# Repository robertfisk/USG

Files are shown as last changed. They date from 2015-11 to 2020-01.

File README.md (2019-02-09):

## The USG is Good, not Bad
The USG is a firewall for your USB ports, protecting your computer from [BadUSB](https://srlabs.de/badusb/). It connects between your computer and your untrusted USB device, isolating the badness and keeping your computer safe.

#### For more info, hit [the Wiki](https://github.com/robertfisk/USG/wiki).

## v1.0 Firmware
This is the firmware branch for the pre-assembled USG v1.0. If you want to build your own USG out of development boards, clone the [v0.9 branch](https://github.com/robertfisk/USG/tree/USG_0.9) instead.

## USG v1.0 hardware
The USG v1.0 is available now from the [online store.](https://globotron.nz/)



## Need More Speed?
The USG is performance-limited due to its USB 1 hardware. If you need to transfer large files from flash drives and hard drives, you need [the Armadillo](https://globotron.nz/products/armadillo-hardware-usb-firewall) instead. Based on the USG's proven open-source technology, the Armadillo is a next-gen device operating at USB 2.0 speed. Available exclusively through the [online store.](https://globotron.nz/products/armadillo-hardware-usb-firewall)



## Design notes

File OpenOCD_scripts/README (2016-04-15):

The OpenOCD scripts in ./board/ are used in-place by the Eclipse debug configurations. You
don't need to copy them anywhere.

If your OpenOCD version is <= 0.8, you will need to copy ./target/stm32f4x.cfg to your OpenOCD
installation's /scripts/target/ folder, replacing the version currently there.
If you have OpenOCD >= 0.9, this is not necessary.

More info for Eclipse OpenOCD configuration:
http://gnuarmeclipse.github.io/debug/openocd/

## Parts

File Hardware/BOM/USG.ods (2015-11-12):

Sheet: Sheet1
Reference | Value | Footprint | Datasheet
U2 | STM32F401xB | USG_footprints:LQFP-64_10x10mm_Pitch0.5mm
C9 | 0.1u | Capacitors_SMD:C_0603
C10 | 0.1u | Capacitors_SMD:C_0603
C11 | 0.1u | Capacitors_SMD:C_0603
C12 | 0.1u | Capacitors_SMD:C_0603
C13 | 0.1u | Capacitors_SMD:C_0603
C5 | 4.7u | Capacitors_SMD:C_0603
C8 | 4.7u | Capacitors_SMD:C_0603
C2 | 18p | Capacitors_SMD:C_0603
C3 | 18p | Capacitors_SMD:C_0603
R5 | 220 | Resistors_SMD:R_0603
Y1 | 8MHz | Crystals:Crystal_HC49-SD_SMD
U3 | AZ1117CH-3.3 | TO_SOT_Packages_SMD:SOT-223
C15 | 22u | Capacitors_SMD:C_0805
C14 | 10u | Capacitors_SMD:C_0805
P1 | USB_A_PLUG | USG_footprints:USB_A_PLUG
R4 | 10k | Resistors_SMD:R_0603
R2 | 1k | Resistors_SMD:R_0603
C1 | 0.1u | Capacitors_SMD:C_0603
BOOT_UPST1 | Jumper_NO_Small | USG_footprints:J_NO_0402
R6 | 10k | Resistors_SMD:R_0603
R8 | 22 | Resistors_SMD:R_0603
R7 | 22 | Resistors_SMD:R_0603
C7 | 0.1u | Capacitors_SMD:C_0603
U1 | NUP4114 | TO_SOT_Packages_SMD:SC-70-6
C6 | 0.1u | Capacitors_SMD:C_0603
JTAG_UPST1 | CONN_02X05 | USG_footprints:Pin_Header_Straight_2x05_Pitch1.27mm
R1 | 220 | Resistors_SMD:R_0603
C4 | 0.1u | Capacitors_SMD:C_0603
FAULT_UPST1 | LED | LEDs:LED-0603
R3 | 1k | Resistors_SMD:R_0603
ID_UPST1 | Jumper_NO_Small | USG_footprints:J_NO_0402
ID_UPST_BOARD0 | Jumper_NC_Small | USG_footprints:J_NC_0402
ID_UPST_BOARD1 | Jumper_NC_Small | USG_footprints:J_NC_0402
ID_UPST_BOARD2 | Jumper_NC_Small | USG_footprints:J_NC_0402
U4 | STM32F401xB | USG_footprints:LQFP-64_10x10mm_Pitch0.5mm
C21 | 0.1u | Capacitors_SMD:C_0603
C22 | 0.1u | Capacitors_SMD:C_0603
C23 | 0.1u | Capacitors_SMD:C_0603
C24 | 0.1u | Capacitors_SMD:C_0603
C25 | 0.1u | Capacitors_SMD:C_0603
C19 | 4.7u | Capacitors_SMD:C_0603
C20 | 4.7u | Capacitors_SMD:C_0603
C17 | 18p | Capacitors_SMD:C_0603
C18 | 18p | Capacitors_SMD:C_0603
R12 | 220 | Resistors_SMD:R_0603
Y2 | 8MHz | Crystals:Crystal_HC49-SD_SMD
P2 | USB_A_SOCKET | USG_footprints:USB_A_SOCKET
R11 | 10k | Resistors_SMD:R_0603
R9 | 1k | Resistors_SMD:R_0603
C16 | 0.1u | Capacitors_SMD:C_0603
BOOT_DNST1 | Jumper_NO_Small | USG_footprints:J_NO_0402
R13 | 10k | Resistors_SMD:R_0603
R15 | 22 | Resistors_SMD:R_0603
R14 | 22 | Resistors_SMD:R_0603
C27 | 0.1u | Capacitors_SMD:C_0603
U5 | NUP4114 | TO_SOT_Packages_SMD:SC-70-6
C26 | 0.1u | Capacitors_SMD:C_0603
JTAG_DNST1 | CONN_02X05 | USG_footprints:Pin_Header_Straight_2x05_Pitch1.27mm
R16 | 220 | Resistors_SMD:R_0603
C28 | 0.1u | Capacitors_SMD:C_0603
FAULT_DNST1 | LED | LEDs:LED-0603
R10 | 1k | Resistors_SMD:R_0603
ID_DNST1 | Jumper_NC_Small | USG_footprints:J_NC_0402
ID_DNST_BOARD0 | Jumper_NC_Small | USG_footprints:J_NC_0402
ID_DNST_BOARD1 | Jumper_NC_Small | USG_footprints:J_NC_0402
ID_DNST_BOARD2 | Jumper_NC_Small | USG_footprints:J_NC_0402
D1 | DOUBLE_DIODE_CCOM | TO_SOT_Packages_SMD:SOT-23
RESET1 | SW_PUSH | USG_footprints:SW_TACT
P3 | USB_OTG | Connect:USB_Micro-B

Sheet: Summarised BOM 1
Reference | Qty | Description | Digikey part | Mfg part
U2, U4 | 2 | STM32F401xB: USG_footprints:LQFP-64_10x10mm_Pitch0.5mm | 497-14047-ND | STM32F401RCT6
C9, C10, C11, C12, C13, C1, C7, C6, C4, C21, C22, C23, C24, C25, C16, C27, C26, C28 | 18 | 0.1u: Capacitors_SMD:C_0603 | 311-1088-1-ND | CC0603KRX7R7BB104
C5, C8, C19, C20 | 4 | 4.7u: Capacitors_SMD:C_0603 | 1276-2087-1-ND | CL10B475KQ8NQNC
C2, C3, C17, C18 | 4 | 18p: Capacitors_SMD:C_0603 | 1276-1089-1-ND | CL10C180JB8NNNC
R5, R1, R12, R16 | 4 | 220: Resistors_SMD:R_0603 | 311-220HRCT-ND | RC0603FR-07220RL
Y1, Y2 | 2 | 8MHz: Crystals:Crystal_HC49-SD_SMD | 535-10212-1-ND | ABLS-8.000MHZ-B4-T
U3 | 1 | AZ1117CH-3.3: TO_SOT_Packages_SMD:SOT-223 | AZ1117CH-3.3TRG1DICT-ND | AZ1117CH-3.3TRG1
C15 | 1 | 22u: Capacitors_SMD:C_0805 | 490-10511-1-ND | GRM21BR61A226ME51L
C14 | 1 | 10u: Capacitors_SMD:C_0805 | 311-1865-1-ND | CC0805KKX5R7BB106
P1 | 1 | USB_A_PLUG: USG_footprints:USB_A_PLUG | 1175-1008-ND | 1001-011-01101
R4, R6, R11, R13 | 4 | 10k: Resistors_SMD:R_0603 | 311-10.0KHRCT-ND | RC0603FR-0710KL
R2, R3, R9, R10 | 4 | 1k: Resistors_SMD:R_0603 | 311-1.00KHRCT-ND | RC0603FR-071KL
R8, R7, R15, R14 | 4 | 22: Resistors_SMD:R_0603 | 311-22.0HRCT-ND | RC0603FR-0722RL
U1, U5 | 2 | NUP4114: TO_SOT_Packages_SMD:SC-70-6 | NUP4114UCW1T2GOSCT-ND | NUP4114UCW1T2G
JTAG_UPST1, JTAG_DNST1 | 2 | CONN_02X05: USG_footprints:Pin_Header_Straight_2x05_Pitch1.27mm | 1175-1627-ND | 3220-10-0100-00
FAULT_UPST1, FAULT_DNST1 | 2 | LED: LEDs:LED-0603 | 160-1434-1-ND | LTST-C190KFKT
P2 | 1 | USB_A_SOCKET: USG_footprints:USB_A_SOCKET | UE27AC54100-ND | UE27AC54100
D1 | 1 | DOUBLE_DIODE_CCOM: TO_SOT_Packages_SMD:SOT-23 | BAV70LT1GOSCT-ND | BAV70LT1G
RESET1 | 1 | SW_PUSH: USG_footprints:SW_TACT | 450-1804-ND | 1825910-7
P3 | 1 | USB_OTG: Connect:USB_Micro-B | 609-4618-1-ND | 10118194-0001LF

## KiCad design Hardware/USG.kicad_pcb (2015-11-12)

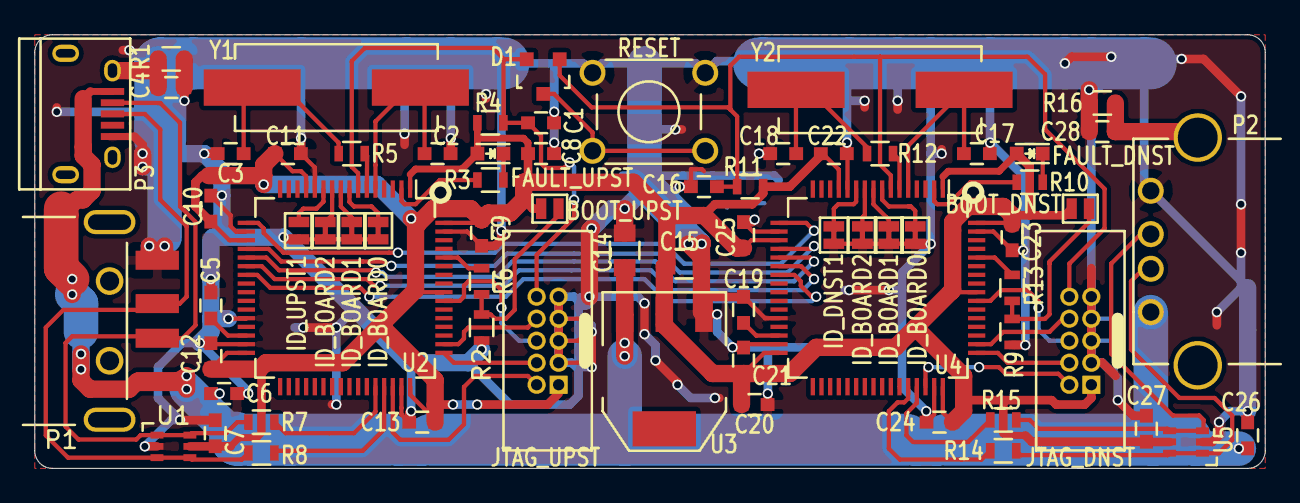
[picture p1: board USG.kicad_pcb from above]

Board: 2 copper layers, 71.0 x 25.0 mm, 70 parts (0 on the bottom side), 53 nets.

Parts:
BOOT_DNST: Jumper_NO_Small; J_NO_0402
BOOT_UPST: Jumper_NO_Small; J_NO_0402
C1, C4, C6, C7, C9, C10, C11, C12, C13, C16, C21, C22, C23, C24, C25, C26, C27, C28: 0.1u; C_0603
C2, C3, C17, C18: 18p; C_0603
C5, C8, C19, C20: 4.7u; C_0603
C14: 10u; C_0805
C15: 22u; C_0805
D1: DOUBLE_DIODE_CCOM; SOT-23
FAULT_DNST: LED; LED-0603
FAULT_UPST: LED; LED-0603
ID_BOARD0, ID_BOARD0#2, ID_BOARD1, ID_BOARD1#2, ID_BOARD2, ID_BOARD2#2: Jumper_NC_Small; J_NC_0402
ID_DNST1: Jumper_NC_Small; J_NC_0402
ID_UPST1: Jumper_NO_Small; J_NO_0402
JTAG_DNST: CONN_02X05; Pin_Header_Straight_2x05_Pitch1.27mm
JTAG_UPST: CONN_02X05; Pin_Header_Straight_2x05_Pitch1.27mm
P1: USB_A_PLUG
P2: USB_A_SOCKET
P3: USB_OTG; USB_Micro-B
R1, R5, R12, R16: 220; R_0603
R2, R3, R9, R10: 1k; R_0603
R4, R6, R11, R13: 10k; R_0603
R7, R8, R14, R15: 22; R_0603
RESET: SW_PUSH; SW_TACT
U1, U5: NUP4114; SC-70-6
U2, U4: STM32F401xB; LQFP-64_10x10mm_Pitch0.5mm
U3: AZ1117CH-3.3; SOT-223
Y1, Y2: 8MHz; Crystal_HC49-SD_SMD

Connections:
+3V3: BOOT_DNST.2, BOOT_UPST.2, C7.1, C8.1, C9.2, C10.2, C11.2, C12.2, C13.2, C15.1, C20.1, C21.2, C22.2, C23.2, C24.2, C25.2, C27.1, FAULT_DNST.2, FAULT_UPST.2, JTAG_DNST.1, JTAG_UPST.1, R4.1, R11.1, U1.5, U2.1, U2.13, U2.19, U2.32, U2.48, U2.56, U2.64, U3.2, U4.1, U4.13, U4.19, U4.32, U4.48, U4.56, U4.64, U5.5
+5V: C6.1, C14.1, C26.1, P1.1, P2.1, P3.1, U3.3
/JTCK_DNST: JTAG_DNST.4, U4.49
/JTCK_UPST: JTAG_UPST.4, U2.49
/JTDI_DNST: JTAG_DNST.8, U4.50
/JTDI_UPST: JTAG_UPST.8, U2.50
/JTDO_DNST: JTAG_DNST.6, U4.55
/JTDO_UPST: JTAG_UPST.6, U2.55
/JTMS_DNST: JTAG_DNST.2, U4.46
/JTMS_UPST: JTAG_UPST.2, U2.46
/RESET_DNST: C16.1, D1.1, JTAG_DNST.10, R11.2, U4.7
/RESET_UPST: C1.1, D1.2, JTAG_UPST.10, R4.2, U2.7
/SPI_MISO: U2.22, U4.22
/SPI_MOSI: U2.23, U4.23
/SPI_NSS: U2.20, U4.20
/SPI_SCK: U2.21, U4.21
/SPI_TX_OK: U2.17, U4.17
GND: C1.2, C2.2, C3.2, C4.2, C5.2, C6.2, C7.2, C8.2, C9.1, C10.1, C11.1, C12.1, C13.1, C14.2, C15.2, C16.2, C17.2, C18.2, C19.2, C20.2, C21.1, C22.1, C23.1, C24.1, C25.1, C26.2, C27.2, C28.2, ID_BOARD0.1, ID_BOARD0#2.1, ID_BOARD1.1, ID_BOARD1#2.1, ID_BOARD2.1, ID_BOARD2#2.1, ID_DNST1.1, ID_UPST1.1, JTAG_DNST.3, JTAG_DNST.5, JTAG_DNST.7, JTAG_DNST.9, JTAG_UPST.3, JTAG_UPST.5, JTAG_UPST.7, JTAG_UPST.9, P1.4, P2.4, P3.5, R1.2, R2.2, R9.2, R16.2, RESET.1, U1.2, U2.12, U2.18, U2.28, U2.31, U2.47, U2.63, U3.1, U4.12, U4.18, U4.28, U4.31, U4.47, U4.63, U5.2
unnamed: BOOT_DNST.1, R9.1, R13.2
unnamed: BOOT_UPST.1, R2.1, R6.2
unnamed: C2.1, U2.5, Y1.1
unnamed: C3.1, R5.2, Y1.2
unnamed: C4.1, P1.5, P3.6, R1.1
unnamed: C5.1, U2.30
unnamed: C17.1, U4.5, Y2.1
unnamed: C18.1, R12.2, Y2.2
unnamed: C19.1, U4.30
unnamed: C28.1, P2.5, R16.1
unnamed: D1.3, RESET.2
unnamed: FAULT_DNST.1, R10.2
unnamed: FAULT_UPST.1, R3.2
unnamed: ID_DNST1.2, U4.11
unnamed: ID_BOARD0.2, U4.8
unnamed: ID_BOARD1.2, U4.9
unnamed: ID_BOARD2.2, U4.10
unnamed: ID_UPST1.2, U2.11
unnamed: ID_BOARD0#2.2, U2.8
unnamed: ID_BOARD1#2.2, U2.9
unnamed: ID_BOARD2#2.2, U2.10
unnamed: P1.2, P3.2, R7.1, U1.1, U1.6
unnamed: P1.3, P3.3, R8.1, U1.3, U1.4
unnamed: P2.2, R14.1, U5.1, U5.6
unnamed: P2.3, R15.1, U5.3, U5.4
unnamed: R3.1, U2.2
unnamed: R5.1, U2.6
unnamed: R6.1, U2.60
unnamed: R7.2, U2.44
unnamed: R8.2, U2.45
unnamed: R10.1, U4.2
unnamed: R12.1, U4.6
unnamed: R13.1, U4.60
unnamed: R14.2, U4.44
unnamed: R15.2, U4.45

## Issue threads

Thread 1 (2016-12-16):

Add small 1GB boot drive for Anti Evil Maid

tasket, 2016-12-16:
It would be nice to have a single device that could both isolate the keyboard and boot the machine via Qubes AEM.

robertfisk, 2016-12-18:
From a purely practical perspective, this can be done for a modest per-unit price by adding a microSD socket to the USG, and connecting it to the downstream (device-side) embedded CPU. This will require another PCB revision with associated prototyping and stock management costs. It would also require extending the internal SPI-bus protocol to support two simultaneous device classes (mass-storage + something else). At the current rate of development this is likely to be 12+ months away :)

**However!** The security implications of this value-add feature should not be underestimated.

1. Obviously there is now no security boundary between your keyboard and your AEM storage. A bad keyboard can attack the SD card's firmware, and potentially vice versa (I'm not sure whether the SD card protocol is sufficiently complex to facilitate an exploit, but USB certainly is).

2. _The killer issue IMO:_ The USG allows only one device to be active at any one time, specifically to block [hidden device attacks.](https://github.com/robertfisk/USG/wiki#type-2-attacks-hidden-evil-functionality) However, implementing microSD card support in the USG firmware means that any badUSB device can now pass through an additional mass storage device at any time. This blows a big hole through the "one active device" rule, and weakens the USG's security stance.

Even simply implementing this feature in an alternative firmware version will lead to reduced trust in the USG. The factory may load in the microSD-supporting fimrware by accident, and the user has no way to verify which firmware was installed without actually exploiting the USG themselves!

So I'm going to leave this issue open, but I will need to address the concerns above before implementing this feature.

virtualguy, 2016-12-18:
How about two downstream microcontrollers, one as a mass storage device and another as the target USB device. Perhaps even on different SPI ports for a little more isolation.

robertfisk, 2016-12-19:
Yes, it would require two downstream MCUs to do this securely. That way the uncompromised upstream MCU can differentiate between a bad keyboard, and legitimate mass storage / SD cards.

Of course this would significantly increase cost, and the PCB will not fit in the current plastic case. It would essentially be an entirely new product.

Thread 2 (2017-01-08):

Upstream Freakout in mass storage mode on Win10

robertfisk, 2017-01-08:
- Connected fat32 formatted flash drive to Win10 machine.
- Got a popup saying drive needs a scan.
- Ignored popup, did not attempt to access the drive.
- Approx 30sec later, Upstream MCU freaked out (red flashing LED on USG v1.0)
- Removed and reinserted flash drive, ran scan as requested, scan finished and everything fine. Cannot trivially reproduce.

Generally speaking, Upstream should not freak out in any circumstance. If I or anyone else sees this happen I will investigate further. Until then this will be a low priority.

robertfisk, 2017-03-12:
Low priority issues have a way of becoming high priority when they keep appearing during production. Argh!

So it turns out this was not specific to Win10, appearing (occasionally) during mass storage writes on any OS. It was caused by unreliable USB host controller operation inside the STM32 with write transactions containing more than one 64-byte packet. Reverting to single-packet writes resolved the issue at the expense of some write speed.

This issue is resolved in firmware release r03.

Closed 2017-03-12.

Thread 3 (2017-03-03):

Implement read-only mass storage mode

robertfisk, 2017-03-03:
Various use-cases (forensics, enhanced paranoia) have a need for a read-only mass storage mode. This could be either a compile-time option, or dynamically set on bootup based on an input pin controlled by the user.

Both Upstream and Downstream would need to be put into read-only mode to ensure robustness in the face of USB exploits coming from either direction.

teeks99, 2017-03-12:
I think this is an awesome idea, this device seems like it would be perfect to implement it. I frequently need to use drives like the [Kanguru](https://www.amazon.com/Kanguru-Solutions-Flash-Write-Protect-KF3WP-32G/dp/B008OGNMEI) with a write-protect switch when transferring data onto a system that stores high-value data. This is done with the hope that if malware were to infect this high-value data system, it wouldn't have any way to ex-filtrate the data. However, ever since the revelation of BadUSB, I've been very worried about a virus being able to just overwrite the firmware to disable the input from this write-protect switch. Even though it is a physical switch, I'm sure that switch doesn't directly control the hardware that charges the write capacitors on the media, or anything like that. I'd bet my bottom dollar that physical switch just gives an input to the firmware...which could be hacked by BadUSB or the like.

However, I'm not sure there would be a benefit in putting downstream (device side) into read-only mode. Does that mean that data couldn't be passed from the mass-storage device to the pc? If so, I believe it would effectively prevent usage of the device completely...don't you need to read data to the file system before you preform writes to the device? I guess you could maybe use that mode to format devices, but even then you'd want some status back.

With the separation of the upstream and downstream sides here, it seems like there would be a place where we could read a switch telling the USG to go to read-only mode for the media, and could then filter any commands coming from the PC sending file data to the media. However, this would need to be in a section of firmware that is protected from manipulation by *either* end of the connection. From reading the documentation I'm unsure if such a place exists on the device. It seems like this is only upstream and downstream firmware, ideally this firewall would be in neither of those as it would be possible for there to be malicious code on *both* ends at the same time. Hope that doesn't grow the scope of the problem too much :-)

robertfisk, 2017-03-15:
I'll take that as a +1 !

I agree that the write protection on common devices is a flag to the firmware, which could be overridden. You can also get forensic 'write blockers'. I have not looked inside one of these, but unless they are built to the same spec as the USG with independent processors, they will also be vulnerable to compromise.

Regarding putting Upstream and Downstream into read-only mode, this would allow reads from the PC through to the device. I agree doing it any other way won't make sense.

Having both Upstream and Downstream agree to disable writes is important in a variety of scenarios:
1. Malware on PC wants to exfiltrate data. Writes are blocked by Upstream.
2. USG-aware malware on PC wants to exfiltrate data. Malware compromises Upstream, but writes are blocked by Downstream.
3. USG-aware BadUSB device wants to disable write protection. BadUSB device compromises Downstream, but writes are blocked by Upstream.

However there is a fourth scenario where things get ugly: USG-aware malware on PC wants to exfiltrate data to USG-aware BadUSB device. In this case both Upstream and Downstream are compromised and we no longer have control. You could have a third 'referee' microcontroller monitoring the SPI bus and blowing the whistle when it sees write commands. But the attacker can easily avoid this by coding a sequence of 'read' commands that actually transmit data to write. In this case we are owned.

So the takeaway is to make sure that the attacker who controls your PC is not cooperating with the attacker who controls your USB storage. Second-sourcing is important!

robertfisk, 2017-07-22:
This feature is now implemented as a compile-time option! Writes can be disabled by commenting out this line...

`#define CONFIG_MASS_STORAGE_WRITES_PERMITTED`

in the files:

`Upstream/Inc/build_config.h`
`Downstream/Inc/build_config.h`

(be sure to make the same change to both files, for maximum malware resistance)

Support for mass storage, keyboards, and mice can be selectively disabled by commenting out other defines in the files above.

Closed 2017-07-22.

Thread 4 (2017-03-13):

Mass storage device reduced size

marmarek, 2017-03-13:
Looks like USG incorrectly send device size information - always it's one block smaller:

Raw device:
```
usb-storage 3-1.2:1.0: USB Mass Storage device detected
scsi host6: usb-storage 3-1.2:1.0
scsi 6:0:0:0: Direct-Access     Generic  Flash Disk       5.00 PQ: 0 ANSI: 2
sd 6:0:0:0: Attached scsi generic sg0 type 0
sd 6:0:0:0: [sda] 4096000 512-byte logical blocks: (2.10 GB/1.95 GiB)
sd 6:0:0:0: [sda] Write Protect is off
sd 6:0:0:0: [sda] Mode Sense: 0b 00 00 08
sd 6:0:0:0: [sda] No Caching mode page found
sd 6:0:0:0: [sda] Assuming drive cache: write through
 sda: sda1
sd 6:0:0:0: [sda] Attached SCSI removable disk
```

With USG:
```
scsi 7:0:0:0: Direct-Access     The USG  is Good, not bad v1.0 PQ: 0 ANSI: 2
sd 7:0:0:0: Attached scsi generic sg0 type 0
sd 7:0:0:0: [sda] 4095999 512-byte logical blocks: (2.10 GB/1.95 GiB)
sd 7:0:0:0: [sda] Write Protect is off
sd 7:0:0:0: [sda] Mode Sense: 00 00 00 00
sd 7:0:0:0: [sda] Asking for cache data failed
sd 7:0:0:0: [sda] Assuming drive cache: write through
 sda: sda1
sda: p1 size 4095968 extends beyond EOD, enabling native capacity
 sda: sda1
sda: p1 size 4095968 extends beyond EOD, truncated
sd 7:0:0:0: [sda] Attached SCSI removable disk
```

robertfisk, 2017-03-14:
It turns out the SCSI ReadCapacity10 command does not return the device capacity. It returns the address of the last block, which is (capacity - 1). I'm totally going to blame ST's USB host stack for this bug! (the USB device stack correctly subtracted one from the block count, hence shrinking devices)

Issue is fixed in tag 1.0r03b.

Closed 2017-03-14.

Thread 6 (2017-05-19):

Initialization problem on v0.9 Upstream board

robertfisk, 2017-05-19:
A user reported their DIY v0.9 running 0.9r03 firmware was not working. Upstream was stuck in the CheckFirmwareMatchesHardware() function on bootup.

We determined this was due to the PC12-pullup check failing (implying that the firmware was not running on a H405 board). Bypassing the PC12 check allowed normal functionality.

We need to determine if this issue can be fixed with a delay in the PC12 check, and how much delay is required. Or whether the issue is due to a logic threshold change, in which case we probably want to find another way to confirm we are running on a H405 board.

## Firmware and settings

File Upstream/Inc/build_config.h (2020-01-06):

/*
 * build_config.h
 *
 *  Created on: Jun 20, 2017
 *      Author: Robert Fisk
 *
 * This Source Code Form is subject to the terms of the Mozilla Public
 * License, v. 2.0. If a copy of the MPL was not distributed with this
 * file, You can obtain one at https://mozilla.org/MPL/2.0/.
 */

#ifndef INC_BUILD_CONFIG_H_
#define INC_BUILD_CONFIG_H_


#define CONFIG_MASS_STORAGE_ENABLED
#define CONFIG_MASS_STORAGE_WRITES_PERMITTED

#define CONFIG_KEYBOARD_ENABLED
#define CONFIG_KEYBOARD_BOT_DETECT_ENABLED

#define CONFIG_MOUSE_ENABLED
#define CONFIG_MOUSE_BOT_DETECT_ENABLED

#define CONFIG_WRITE_FLASH_TIME_MS                          3000        //Enable write LED flashes for the specified length of time



//Configure keyboard bot detection here:
#ifdef CONFIG_KEYBOARD_BOT_DETECT_ENABLED
    //-----------------------------------------------------------
    //Adjust this threshold first to tune keyboard bot detection. Lower values = more sensitive
    #define KEYBOARD_BOTDETECT_LOCKOUT_BIN_THRESHOLD        5       //4 is a good setting for the paranoid. 5 is good for the average user who doesn't want to encounter a rare false-positive.
    //-----------------------------------------------------------

    #define KEYBOARD_BOTDETECT_FAST_BIN_WIDTH_MS            10      //10ms per bin
    #define KEYBOARD_BOTDETECT_SLOW_BIN_WIDTH_MS            20      //20ms per bin
    #define KEYBOARD_BOTDETECT_FAST_BIN_COUNT               30      //30 bins at 10ms = 300ms fast coverage
    #define KEYBOARD_BOTDETECT_SLOW_BIN_COUNT               50      //50 bins at 20ms = 1 sec slow coverage, wrapped
    #define KEYBOARD_BOTDETECT_FAST_BIN_DRAIN_DIVIDER       2
    #define KEYBOARD_BOTDETECT_SLOW_BIN_DRAIN_DIVIDER       4
#endif


//Configure mouse bot detection here:
#ifdef CONFIG_MOUSE_BOT_DETECT_ENABLED
    #define MOUSE_BOTDETECT_VELOCITY_MULTIPLIER             10

    //Jump detection stuff
    #define MOUSE_BOTDETECT_JUMP_VELOCITY_THRESHOLD         20      //Varies by mouse. Most short jumps are <= 10 velocity
    #define MOUSE_BOTDETECT_JUMP_PERIODS                    4

    //Constant acceleration detection stuff
    #define MOUSE_BOTDETECT_CONSTANT_ACCEL_LOCKOUT          300     //Lock when constant acceleration counter reaches this number
    #define MOUSE_BOTDETECT_CONSTANT_ACCEL_STOP             100     //Block mouse movements when counter is above this value
    #define MOUSE_BOTDETECT_CONSTANT_ACCEL_CREDIT           100     //Non-constant-acceleration movements can build a credit that will be used before hitting the limits above. Handy for mice or users that exhibit constant velocity characteristics mid-movement.
    #define MOUSE_BOTDETECT_VELOCITY_RESET_TIMEOUT_MS       3000    //Reset constant acceleration counter when mouse stops for this time

    #define MOUSE_BOTDETECT_VELOCITY_HISTORY_SIZE           12
    #define MOUSE_BOTDETECT_VELOCITY_MATCH_BASE             256
    #define MOUSE_BOTDETECT_VELOCITY_MATCH_ERROR            6

    //Jiggle detection stuff
    #define MOUSE_BOTDETECT_JIGGLE_STOP_PERIODS             10
    #define MOUSE_BOTDETECT_JIGGLE_BIN_WIDTH_MS             20      //20ms per bin
    #define MOUSE_BOTDETECT_JIGGLE_BIN_COUNT                50      //50 bins at 20ms = 1 sec coverage, wrapped
    #define MOUSE_BOTDETECT_JIGGLE_BIN_DIVIDER              3
    #define MOUSE_BOTDETECT_LOCKOUT_JIGGLE_BIN_THRESHOLD    4
#endif


//Configuration common to all bot detectors
#if defined CONFIG_KEYBOARD_BOT_DETECT_ENABLED || defined CONFIG_MOUSE_BOT_DETECT_ENABLED
    #define BOTDETECT_TEMPORARY_LOCKOUT_TIME_MS             4000    //Lock keyboard/mouse for 4 seconds as a first warning
    #define BOTDETECT_TEMPORARY_LOCKOUT_FLASH_TIME_MS       60000   //Flash fault LED for 60 seconds after warning lockout
#endif


#endif /* INC_BUILD_CONFIG_H_ */

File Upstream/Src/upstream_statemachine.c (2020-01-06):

/*
 * upstream_statemachine.c
 *
 *  Created on: 20/08/2015
 *      Author: Robert Fisk
 *
 * This Source Code Form is subject to the terms of the Mozilla Public
 * License, v. 2.0. If a copy of the MPL was not distributed with this
 * file, You can obtain one at https://mozilla.org/MPL/2.0/.
 */


#include "upstream_statemachine.h"
#include "upstream_spi.h"
#include "upstream_hid.h"
#include "usb_device.h"
#include "usbd_core.h"
#include "usbd_msc.h"
#include "usbd_hid.h"
#include "build_config.h"

#define POLL_DEVICE_CONNECTED_TIMEOUT_MS    1000


UpstreamStateTypeDef            UpstreamState           = STATE_TEST_INTERFACE;
InterfaceCommandClassTypeDef    ConfiguredDeviceClass   = COMMAND_CLASS_INTERFACE;
uint32_t                        PollDeviceConnectedTimer;


void Upstream_StateMachine_TestInterfaceReplyCallback(UpstreamPacketTypeDef* replyPacket);
void Upstream_StateMachine_NotifyDevice(UpstreamPacketTypeDef* freePacket);
void Upstream_StateMachine_NotifyDeviceReplyCallback(UpstreamPacketTypeDef* replyPacket);
void Upstream_StateMachine_PollDeviceConnectedReplyCallback(UpstreamPacketTypeDef* replyPacket);



void Upstream_InitStateMachine(void)
{
    UpstreamPacketTypeDef* freePacket;
    uint16_t i;
    uint8_t  testDataValue;

    Upstream_InitSPI();

    //Prepare SPI test packet
    freePacket = Upstream_GetFreePacketImmediately();
    if (freePacket == NULL)
    {
        UpstreamState = STATE_ERROR;
        return;
    }

    freePacket->Length16 = UPSTREAM_PACKET_LEN_16;
    freePacket->CommandClass = COMMAND_CLASS_INTERFACE;
    freePacket->Command = COMMAND_INTERFACE_ECHO;

    //Fill our test packet with some junk
    testDataValue = 0xFF;
    for (i = 0; i < MSC_MEDIA_PACKET; i++)
    {
        freePacket->Data[i] = testDataValue;
        testDataValue += 39;
    }

    if (Upstream_TransmitPacket(freePacket) == HAL_OK)
    {
        Upstream_ReceivePacket(Upstream_StateMachine_TestInterfaceReplyCallback);
    }
}


//Used by upstream_spi freakout macro, indicates we should stop everything.
void Upstream_StateMachine_SetErrorState(void)
{
    UpstreamState = STATE_ERROR;
    if ((ConfiguredDeviceClass > COMMAND_CLASS_INTERFACE) &&
        (ConfiguredDeviceClass < COMMAND_CLASS_ERROR))
    {
        USBD_DeInit(&hUsbDeviceFS);
    }
}


InterfaceCommandClassTypeDef Upstream_StateMachine_CheckActiveClass(void)
{
    if (UpstreamState == STATE_ERROR)
    {
        return COMMAND_CLASS_ERROR;
    }

    if ((UpstreamState == STATE_DEVICE_ACTIVE) ||
        (UpstreamState == STATE_SUSPENDED))
    {
        return ConfiguredDeviceClass;
    }

    //else:
    UPSTREAM_STATEMACHINE_FREAKOUT;
    return COMMAND_CLASS_INTERFACE;
}


uint32_t Upstream_StateMachine_GetSuspendState(void)
{
    if (UpstreamState == STATE_SUSPENDED)
    {
        return 1;
    }
    return 0;
}


void Upstream_StateMachine_TestInterfaceReplyCallback(UpstreamPacketTypeDef* replyPacket)
{
    uint16_t i;
    uint8_t  testDataValue;

    if (UpstreamState >= STATE_ERROR)
    {
        return;
    }

    if ((UpstreamState != STATE_TEST_INTERFACE) ||
        (replyPacket == NULL))
    {
        UPSTREAM_STATEMACHINE_FREAKOUT;
        return;
    }

    if (replyPacket->Length16 != UPSTREAM_PACKET_LEN_16)
    {
        UPSTREAM_STATEMACHINE_FREAKOUT;
        return;
    }

    testDataValue = 0xFF;
    for (i = 0; i < MSC_MEDIA_PACKET; i++)
    {
        if (replyPacket->Data[i] != testDataValue)
        {
            UPSTREAM_STATEMACHINE_FREAKOUT;
            return;
        }
        testDataValue += 39;
    }

    //SPI interface passed checks. Now we wait for a device to be attached to downstream.
    Upstream_StateMachine_NotifyDevice(replyPacket);
}


void Upstream_StateMachine_NotifyDevice(UpstreamPacketTypeDef* freePacket)
{
    UpstreamState = STATE_WAIT_DEVICE;
    freePacket->Length16 = UPSTREAM_PACKET_HEADER_LEN_16;
    freePacket->CommandClass = COMMAND_CLASS_INTERFACE;
    freePacket->Command = COMMAND_INTERFACE_NOTIFY_DEVICE;
    if (Upstream_TransmitPacket(freePacket) == HAL_OK)
    {
        Upstream_ReceivePacket(Upstream_StateMachine_NotifyDeviceReplyCallback);
    }
}


void Upstream_StateMachine_NotifyDeviceReplyCallback(UpstreamPacketTypeDef* replyPacket)
{
    InterfaceCommandClassTypeDef newActiveClass = COMMAND_CLASS_INTERFACE;
    USBD_ClassTypeDef*           newClassPointer;

    if (UpstreamState >= STATE_ERROR)
    {
        return;
    }

    if ((UpstreamState != STATE_WAIT_DEVICE) ||
        (replyPacket == NULL))
    {
        UPSTREAM_STATEMACHINE_FREAKOUT;
        return;
    }

    if (replyPacket->Length16 != (UPSTREAM_PACKET_HEADER_LEN_16 + 1))
    {
        UPSTREAM_STATEMACHINE_FREAKOUT;
        return;
    }

    switch (replyPacket->Data[0])
    {
#ifdef CONFIG_MASS_STORAGE_ENABLED
    case COMMAND_CLASS_MASS_STORAGE:
        newActiveClass = COMMAND_CLASS_MASS_STORAGE;
        newClassPointer = &USBD_MSC;
        break;
#endif
#ifdef CONFIG_MOUSE_ENABLED
    case COMMAND_CLASS_HID_MOUSE:
        newActiveClass = COMMAND_CLASS_HID_MOUSE;
        newClassPointer = &USBD_HID;
        USBD_HID_PreinitMouse();
        break;
#endif
#ifdef CONFIG_KEYBOARD_ENABLED
    case COMMAND_CLASS_HID_KEYBOARD:
        newActiveClass = COMMAND_CLASS_HID_KEYBOARD;
        newClassPointer = &USBD_HID;
        USBD_HID_PreinitKeyboard();
        break;
#endif
        //Add other supported classes here...
    }

    Upstream_ReleasePacket(replyPacket);

    if (newActiveClass == COMMAND_CLASS_INTERFACE)
    {
        UPSTREAM_STATEMACHINE_FREAKOUT;
        return;
    }

    //Downstream should never change the active device class without rebooting!
    if ((ConfiguredDeviceClass != COMMAND_CLASS_INTERFACE) &&
        (ConfiguredDeviceClass != newActiveClass))
    {
        UPSTREAM_STATEMACHINE_FREAKOUT;
        return;
    }

    UpstreamState = STATE_DEVICE_ACTIVE;
    ConfiguredDeviceClass = newActiveClass;
    USB_Device_Init();
    USBD_RegisterClass(&hUsbDeviceFS, newClassPointer);
    USBD_Start(&hUsbDeviceFS);

    //The USB device stack will now receive commands from our host.
    //All we need to do is monitor for downstream device disconnection.
}


void Upstream_StateMachine_DeviceDisconnected(void)
{
    if ((ConfiguredDeviceClass == COMMAND_CLASS_INTERFACE) ||
        (ConfiguredDeviceClass >= COMMAND_CLASS_ERROR))
    {
        UPSTREAM_STATEMACHINE_FREAKOUT;
        return;
    }

    USBD_DeInit(&hUsbDeviceFS);
    Upstream_GetFreePacket(Upstream_StateMachine_NotifyDevice);
}


//Suspend event activated by our host
void Upstream_StateMachine_Suspend(void)
{
    if (UpstreamState >= STATE_SUSPENDED)       //Ignore when already suspended, or in error state
    {
        return;
    }
    if (UpstreamState != STATE_DEVICE_ACTIVE)
    {
        UPSTREAM_STATEMACHINE_FREAKOUT;
        return;
    }

    PollDeviceConnectedTimer = 0;
    UpstreamState = STATE_SUSPENDED;
}
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

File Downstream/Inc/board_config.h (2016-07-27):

/*
 * board_config.h
 *
 *  Created on: 25/03/2015
 *      Author: Robert Fisk
 *
 * This Source Code Form is subject to the terms of the Mozilla Public
 * License, v. 2.0. If a copy of the MPL was not distributed with this
 * file, You can obtain one at https://mozilla.org/MPL/2.0/.
 */


#ifndef INC_BOARD_CONFIG_H_
#define INC_BOARD_CONFIG_H_


#define BSRR_SHIFT_HIGH         0
#define BSRR_SHIFT_LOW          16

#define PA_JTMS                 GPIO_PIN_13
#define PA_JTCK                 GPIO_PIN_14
#define PA_JTDI                 GPIO_PIN_15
#define PB_JTDO                 GPIO_PIN_3
#define PB_NJTRST               GPIO_PIN_4

#define FAULT_LED_PIN           GPIO_PIN_13
#define FAULT_LED_PORT          GPIOC
#define FAULT_LED_ON            (FAULT_LED_PORT->BSRR = (FAULT_LED_PIN << BSRR_SHIFT_LOW))  //Fault LED is active-low
#define FAULT_LED_OFF           (FAULT_LED_PORT->BSRR = (FAULT_LED_PIN << BSRR_SHIFT_HIGH))

#define H405_FAULT_LED_PIN      GPIO_PIN_12     //Fault LED on Olimex H405 board
#define H405_FAULT_LED_ON       (FAULT_LED_PORT->BSRR = (H405_FAULT_LED_PIN << BSRR_SHIFT_LOW))

#define INT_ACTIVE_PIN          GPIO_PIN_2      //Temporary indicator of SPI (or whatever) activity
#define INT_ACTIVE_PORT         GPIOA
#define INT_ACTIVE_ON           INT_ACTIVE_PORT->BSRR = (INT_ACTIVE_PIN << BSRR_SHIFT_HIGH)
#define INT_ACTIVE_OFF          INT_ACTIVE_PORT->BSRR = (INT_ACTIVE_PIN << BSRR_SHIFT_LOW)

//#define SPI1_NSS_PIN          GPIO_PIN_4
//#define SPI1_NSS_PORT         GPIOA

#define UPSTREAM_TX_REQUEST_PIN         GPIO_PIN_3
#define UPSTREAM_TX_REQUEST_PORT        GPIOA
#define UPSTREAM_TX_REQUEST_ASSERT      (UPSTREAM_TX_REQUEST_PORT->BSRR = (UPSTREAM_TX_REQUEST_PIN << BSRR_SHIFT_LOW))
#define UPSTREAM_TX_REQUEST_DEASSERT    (UPSTREAM_TX_REQUEST_PORT->BSRR = (UPSTREAM_TX_REQUEST_PIN << BSRR_SHIFT_HIGH))

#define DBGMCU_IDCODE_DEV_ID_405_407_415_417    0x413
#define DBGMCU_IDCODE_DEV_ID_401xB_xC           0x423

#define BOARD_REV_PIN_MASK      0x07
#define BOARD_ID_PIN_MASK       0x08
#define BOARD_REV_ID_PORT       GPIOC

#define BOARD_REV_1_0_BETA      0
#define BOARD_REV_1_0_BETA_3    1

#define BOARD_REV_1_0_BETA_FREQ     8
#define BOARD_REV_1_0_BETA_3_FREQ   16


#endif /* INC_BOARD_CONFIG_H_ */

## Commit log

2015-06-04 Initial commit!
    Upstream (device) firmware builds, emulates a small USB block device
    filled with zeroes.
2015-06-04 Add OpenOCD config file for Olimex STM32-H405 development board.
    [olimex_stm32_h405.cfg]
2015-07-16 Draft implementation of downstream SPI interface. Significant mods required to USB MSC class, mainly in usbd_msc_scsi.c. Currently untested!
2015-07-19 Upstream debugged and working again, emulating a 128MB storage device.
    Implemented mock downstream_interface_msc.c for debugging purposes.
    Multiple bugfixes and tweaks to:
    - downstream_interface_msc.c
    - downstream_spi.c
    - usbd_core.c
    - usbd_msc.c
    - usbd_msc_scsi.c
    - stm32f4xx_hal_pcd.c
    [board_config.h, downstream_spi.c, hal_msp.c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]
2015-07-20 Updated STM32 library from v1.4.0 to v1.7.0
    Significant changes to:
    - stm32f4xx_hal_spi.c
    - stm32f4xx_hal_gpio.c
    - stm32f4xx_ll_usb.c
    - usbd_ctrlreq.c
    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
2015-07-21 Initial commit of Downstream template project.
    [olimex_stm32_h407.cfg]
2015-08-02 Refactor a bunch of stuff in Upstream project to avoid endless confusion with Downstream project.
    Also fixed a couple of things in upstream_spi.c and
    upstream_interface_msc.c but due to file rename the diff is not
    obvious...
    [interrupts.c, upstream_interface_msc.c, upstream_interface_msc_mock.c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]
2015-08-08 Initial implementation of Downstream SPI interface and state machine.
2015-08-13 Commit of Downstream before diving into USB MSC class driver modifications.
    Also correct project settings to compile for Cortex M4 architecture.
    [downstream_interface_def.h, downstream_msc.c]
2015-08-20 Improved Downstream error handling:
    - More sensible handling of error cases on SPI interface
    - Improved Freakout macros
    - Implemented automatic fault LED blinking
    [board_config.h, downstream_msc.c, downstream_spi.c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]
2015-08-20 Added priority elevation to Downstream USB host processing code that interacts with SPI.
    It elevates to USB_OTG priority to avoid preemption by SPI, DMA, or USB
    interrupts thus avoiding synchronisation issues between USB host stack
    and SPI interface.
    Also minor improvements to Downstream error handling.
2015-08-22 Revisit Upstream project to: - Implement Upstream state machine, with Downstream-dependent device emulation - Add fault LED flashing - Improve fault handling and freakouts - Misc bug fixes
    [board_config.h, downstream_spi.c, interrupts.c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]
2015-08-23 - Implement notification of Downstream USB device removal, and corresponding Upstream disconnection - Improve Upstream handling of TxOk signal from Downstream - Misc tweaks
2015-08-24 Bugfixes for Downstream, including one in the USB host stack!
    Downstream now enumerates and accepts attached USB storage devices.
    [downstream_msc.c]
2015-09-30 Crazy hardware issues, about to revert Upstream SPI from DMA to interrupt transfers
    [board_config.h, downstream_msc.c, downstream_spi.c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]
2015-10-01 Completed moving Upstream to interrupt-based SPI.
    Although I am not entirely convinced this is necessary, as the SPI data
    stall issue only appeared with optimisation off (-O0). Perhaps re-visit
    this if Upstream needs more free CPU time later...
    [board_config.h, downstream_spi.c, hal_msp.c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]
2015-10-03 Code tidyup - remove unused SPI Tx-only and Rx-only routines
2015-10-03 Increase SPI interface speed 4x, to 5.25Mbps. Required modifications to SPI peripheral library. At this speed SPI requires ~60% CPU time at -Og optimisation level. This could be further improved by t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
    Speed is now limited by Downstream's single-packet-per-URB restriction,
    to about 460kB/s. USB Middleware does not implement TX FIFO empty
    interrupt, so a bit of work is required here.
2015-10-03 Added Mozilla Public License information to file headers.
    Mozilla Public License v2.0 is compatible with the various licenses used
    by ST and ARM.
2015-10-04 Tidy up commented DMA init code
2015-10-11 Improve Downstream error handling:
    - Slow flash fault LED when unsupported device connected
    - Disconnect downstream USB host on error
2015-10-12 Previous commit missed an unsupported-device-flash-LED check.
    NOTE: Downstream's full-speed host controller is flakey when connecting
    to low-speed devices. One mouse enumerates on only 50% of connection
    events, while another mouse enumerates on 90% of connections. Grrr.
2015-10-17 Two bugfixes for Upstream's SPI packet handling:
    - Use asynchronous free packet callback for Upstream_MSC_BeginRead
    - Upstream_MSC_BeginWrite freed packet too early
    [upstream_msc.c]
2015-11-07 Changed Upstream and Downstream SPI transfers back to DMA. DMA works correctly now, either because SPI is in 16-bit mode, or because I found all the other bugs!
    Doubled SPI baudrate to 10.5Mbps. Transfer speed now limited (again) by
    Downstream's lack of FIFO buffering in the USB host controller.
    Also disabled DMA transaction half-complete interrupt in
    stm32f4xx_hal_dma.c, as it wasn't doing anything useful.
    [board_config.h, downstream_spi.c, hal_msp.c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]
2015-11-08 Added hardware check on bootup: fault LED will light if Upstream firmware is placed on Downstream hardware or vice versa.
2015-11-12 Initial commit of v1.0 hardware. Schematic done, layout in progress.
    [USG.kicad_pcb, USG.sch]
2015-11-12 Hardware v1.0 beta complete, ready for fabrication
    [USG-B_Cu.gbl, USG-B_Mask.gbs, USG-B_SilkS.gbo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]
2015-11-12 Added BOM with Digikey part numbers, and a cool part-combinater-o-tron macro.
    Also zipped the gerbers.
    [USG.ods]
2015-11-12 Modify firmware for v1.0 hardware with STM32F401RC micro: - Processor-specific header - Startup file - Linker script - Project settings - Debugger config script - Debugger project settings - Board re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
    [olimex_stm32_h405.cfg, olimex_stm32_h407.cfg]
2015-11-14 USG v1.0 beta WORKS!!!!!11
    So apparently the STM32F401's SPI DMA is even more buggy than the 405's.
    Worked around an intermittent stall/timeout by busy-waiting Upstream's
    packet length transmission and reception, instead of DMA-ing it like the
    packet body. Ugh...
    [upstream_spi.c]
2015-11-15 Implement flash write lockout by spamming the unlock register, then checking that the correct unlock sequence fails.
    [interrupts.c]
2015-11-17 Supported device classes that fail sanity checks are now reported with a slow 'unsupported device' flash, rather than a fast 'freakout' flash.
2016-01-02 Initial commit of ST Cube HID drivers
2016-01-02 Revert "Initial commit of ST Cube HID drivers"
    This reverts commit 08068c25d4e4ad86922be2490401426a021bdd1a.
2016-01-03 Tweak device descriptor strings
2016-04-10 Downstream HID SPI interface done, untested.
2016-04-14 Restructure & bugfix Upstream HID. Still some issue with Downstream...
    [downstream_hid.c, downstream_interface_def.h, upstream_msc.c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]
2016-04-15 Mouse WORKS!11111 ...but only in boot mode, so no scroll wheel :(
2016-04-15 Fixed bug in Upstream MSC. I have no idea why it worked before...
    [upstream_msc.c]
2016-04-24 Fixed enumeration issues with low-speed devices:
    - Unexpected second port-connected interrupt on cold boot with low-speed
    device connected.
    - Retry on failure to get device descriptor. (We still fail after three
    attempts, but that is better than failing after the first one!)
    Also changed eclipse project to use external builder.
    [usbh_config.c]
2016-04-25 More work on enumerating cheap POS mice, arrrrgh.
    Added timeout checks and retry functionality to control transaction
    state machine. But some times the device just won't talk, so we flash
    the fault LED slowly to give the user some clue about what happened.
    [usbh_config.c]
2016-04-26 Fixed click-drag issue.
    TODO: find out why 8-byte device interrupt endpoints totally fail.
    WTF???
    [downstream_hid.c]
2016-04-27 HID parser and wheel support works!
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2016-05-03 Implement multi-PID support so that Windows will recognise each device class as a separate device.
2016-05-03 Improve HID parser error checking
    [downstream_hid.c]
2016-05-08 Sleep instead of busy-wait, approx 50% power reduction!
2016-05-31 Implemented FIFO support in Downstream host, significant speed increase!
    Each USB transaction passed to the driver now consists of multiple
    64-byte packets. 8 packets when receiving, 4 packets when transmitting.
    The STM32 silicon bugs out when more than 4 packets are scheduled to
    write at a time :(
    Reads 1.0MB/sec, writes 967kB/sec, not CPU limited :)
2016-07-27 Implement dynamic crystal frequency selection based on board revision.
    Also fixed minor issue in hardware revision-detection function.
    [board_config.h, hal_msp.c]
2016-08-20 Fix for occasional timeout on writes...
    ...Downstream was not always changing state correctly after closely
    spaced interrupts.
    Also improve flash-write-lockout function to avoid dependency on
    optimisation level.
    [interrupts.c]
2016-08-21 Fix dynamic crystal frequency detection based on board revision
2016-08-27 Fix for occasional problem when attaching mouse after powerup.
    It turned out we were getting a "device disconnected" interrupt while
    waiting for the port to enable following reset. Simply ignoring the
    disconnect interrupt allows everything to work! WTF...
    [usbh_config.c]
2016-08-27 Bugfix to allow reconnecting HID devices
2016-09-04 Bugfixes for keyboard support: works!!!
    [downstream_hid.c]
2016-09-05 Don't fail if device stalls on SetIdle command (*cough* Logitech mice)
2016-10-02 After an epic battle, suspend/resume/wakeup is now supported.
    It turns out that suspend support on the STM32 USB core is buggy as
    heck. Host mode cannot resume after suspend, and device mode cannot
    receive resume or send wakeup signalling.
    I managed to fake resume support by keeping Downstream and our connected
    device running at full power, and simulating a wakeup event to the host
    by disconnecting/reconnecting Upstream from the host.
    [upstream_statemachine.c]
2016-10-22 Don't freakout when wakeup-from-sleep fails during keyboard report out.
    [upstream_statemachine.c]
2016-10-23 Correctly parse HID report descriptor items with unusual lengths.
    Thanks Logitech.
    [downstream_hid.c]
2016-10-23 Correctly resume operation after HID device unplug/replug
2016-10-23 Startup LED flash is now asynchronous.
    Not only a faster startup process, but also catches some HID devices
    that only work if initialised within 500ms of powerup.
2016-12-16 Remove obsolete kicad library from beta 1 project
2017-03-07 Fix for occasional freakouts on mass storage writes.
    Upstream's edge-detect interrupt that starts SPI transmission was not
    firing. Sometimes. On some boards only. The cause was Downstream not
    allowing enough time between edges for Upstream to catch the signal.
    Also misc code tidyups.
    [downstream_spi.c, upstream_spi.c]
2017-03-10 Fix for the previous fix. This time for sure.
    Previously we wrote 4 x 64 byte transactions to the downstream device.
    This is fast, but very occasionally the USB host silicon would bug out.
    Reverting to single 64 byte write transactions increases reliability at
    the expense of some write speed.
2017-03-14 Fixed devices-shrinking-by-one-block problem.
    So it turns out the SCSI ReadCapacity10 command does not return the
    device capacity. It returns the address of the last block, which is
    (capacity - 1).
    Also fixed Upstream's end-of-device sanity check.
2017-08-21 HID keyboard bot detection mostly implemented. Needs more advanced LED flash code, and testing.
2017-10-22 HID BotDetect functionality debugged and working:
    - Implement advanced LED flash support
    - Tweak HAL_SPI_TransmitReceive to tolerate a longer SysTick interrupt
    - Tune KEYBOARD_BOTDETECT parameters
    - L-shift and R-shift are now high-speed alphanumeric keys
2017-11-20 Added error band comparison to velocity matching
    [build_config.h]
2018-01-05 Implement mouse acceleration pulse timing. Doesn't work on realistic inputs.
    [build_config.h]
2018-01-08 Implement random-movement credit in the constant acceleration detector.
    This makes it more forgiving of constant acceleration mid-movement, if
    the beginning of the movement looks random. Handy for mice that for some
    reason generate bot-like constant velocities.
2018-01-09 Reset mouse velocity history on each movement
    [build_config.h]
2018-01-13 Restore jiggle detection.
    This is no longer taken care of by the constant acceleration detector,
    so we need to do it explicitly
    [build_config.h]
2018-01-15 Better support for multi-interface HID: Logitech unifying receivers
    - Select mouse interface first
    - Correctly specify active interface when retrieving HID descriptors
    [usbh_config.h]
2018-01-19 Jump detection now measures entire length of movement, not just the proportion above the jump velocity threshold.
    Also tweaked constant acceleration parameters.
2018-04-02 Don't overwrite array bounds when mass storage device reports > 2 LUNs
2020-01-05 Retry control requests for slow flash drives
    Conflicts:
    Downstream/Middlewares/ST/STM32_USB_Host_Library/Core/Src/usbh_ctlreq.c
2020-01-05 Don't spam device while waiting for MSC unit ready
    Downstream/Middlewares/ST/STM32_USB_Host_Library/Class/MSC/Src/usbh_msc.c
    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
2020-01-06 Implemented Stop/Eject command passthrough
    Downstream/.cproject
    Downstream/Inc/downstream_interface_def.h
    Downstream/Middlewares/ST/STM32_USB_Host_Library/Class/MSC/Src/usbh_msc_scsi.c
    Downstream/Src/downstream_msc.c
    Upstream/Inc/upstream_interface_def.h
    Upstream/Inc/upstream_msc.h
    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
2020-01-06 Correctly handle reads/writes after stop command issued.
    Also correctly report device disconnection if Upstream polls too slowly.
    Downstream/Src/downstream_statemachine.c
    Upstream/Middlewares/ST/STM32_USB_Device_Library/Class/MSC/Src/usbd_msc_scsi.c
    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
2020-01-06 Poll mass storage for disconnection while suspended - fix for Windows 'safely remove' function.
    [downstream_interface_def.h, downstream_msc.c]
2020-01-06 Wait for phantom Connect interrupts to finish before completing Disconnect processing
    Downstream/Middlewares/ST/STM32_USB_Host_Library/Core/Src/usbh_core.c
    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
2020-01-06 Implement read/write indication on the fault LEDs
    Downstream/Inc/build_config.h
    Downstream/Src/led.c
    Upstream/Inc/build_config.h
    Upstream/Src/led.c
    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
2020-01-06 Fix LED includes
2020-01-06 Correctly ignore bogus suspend messages on device reconnect
